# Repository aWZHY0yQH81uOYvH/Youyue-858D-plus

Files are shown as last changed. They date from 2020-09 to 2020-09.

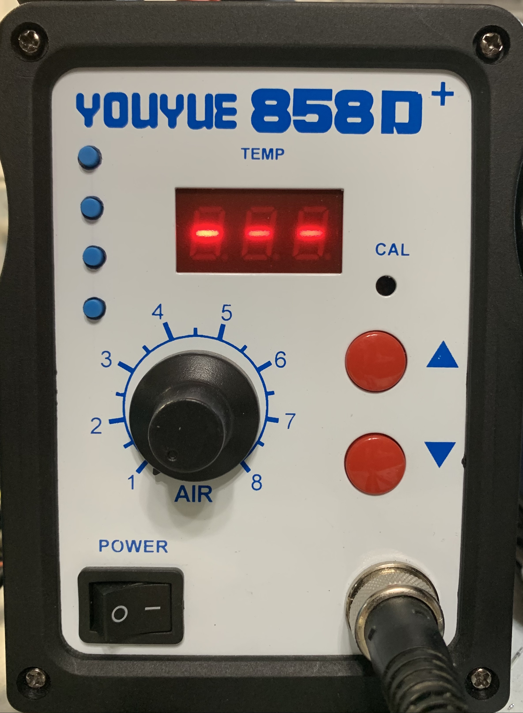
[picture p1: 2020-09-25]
Docs/mods/preset-buttons/front panel.jpg

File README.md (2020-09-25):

Youyue-858D-plus
================

Custom firmware and adapter PCB for the Youyue 858D+ with MK1841D3 stock MCU

This board and firmware is designed only for the ATmega328*PB* because it makes use of its extra port E I/O.

This repo includes a PCB that contains all the mods I could find:
* wguibas's MK1841D3 to AVR pinout adapting
* madworm's fancy fan speed commutation sensing
* RaiHei's buzzer
* Gabse's max fan speed cooldown
* 4 buttons for recalling preset temperatures
* Some extra I/O breakout for more hacking

Order the parts and PCB in the PCB folder. Then, use [this instructable](https://www.instructables.com/id/858D-SMD-Hot-Ait-Reflow-Station-Hack/) as a general guide. Add some buttons to the front panel for the presets.

There is a 'user manual' of sorts in the 'Docs' folder.

Some videos showing the progress from 'stock firmware' with massive temperature overshoot
towards almost no overshoot at all.

https://www.youtube.com/playlist?list=PLONcxJMOrdyeYuEgM6qhCllZelN6gPjrT

Please note:

Although this device looks very much like ones sold by 'Atten' and others, the innards
are not necessarily the same. The heater / wand are probably the same, but I know that
e.g. the 'Atten 858D' uses a different mainboard with a different brand microcontroller.

Naturally, this firmware will only work 'as is' for the exact mcu / mainboard combination I have.
Please see the 'Docs' folder for schematic and PCB photos.

Compiling/Development
=====================
Since this version of the firmware uses the PB variant of the chip, you need to use the makefile. You may need to adjust `ISP_PROG` and `AVRDUDE_ARD_PROGRAMMER` in the makefile depending on what programmer you have.
* Do `make` to just compile the project.
* Do `make ispload` to compile and upload the project.
* If you don't want to edit the firmware, you can just follow the instructions in the binaries folder to upload without compiling.

---

Safety information / disclaimer:
================================

Making any modifications to this device may cause you irreversible physical harm or worse.
You do this at your own risk. 

There is a significant risk of lethal electrical shock, so if you still insist of doing so, make sure to
ALWAYS UNPLUG THE MAINS CABLE before dismantling the device. Check repeatedly.

If you have an isolation transformer - do use it.

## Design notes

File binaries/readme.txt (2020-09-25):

Programming
===========

Fuses
=====

AVRDUDE command line for writing the FUSE settings to the chip (required once):

avrdude -C avrdude.conf -c <programmer> -P <port,optional> -p <target-mcu> -v -U lfuse:w:0xAA:m -U hfuse:w:0xBB:m -U efuse:w:0xCC:m -U lock:w:0xDD:m

EX: avrdude -C avrdude.conf -p m328pb -c atmelice_isp -U lfuse:w:0xE2:m -U hfuse:w:0xDF:m -U efuse:w:0xfd:m

It's okay if the extended fuses fail verification because some of them are undefined.

L-FUSE: 0xE2
H-FUSE: 0xDF
E-FUSE: 0xFD

AVR FUSE calculator:
====================

(1) http://www.engbedded.com/fusecalc
(2) http://eleccelerator.com/fusecalc/fusecalc.php

Flashing
========

AVRDUDE command line for writing code to the chip:

avrdude -C avrdude.conf -c <programmer> -P <port,optional> -p <target-mcu> -v -e -U flash:w:<hexfile>:i

EX: avrdude -C avrdude.conf -p m328pb -c atmelice_isp -U flash:w:build-uno/Youyue-858D-plus.hex

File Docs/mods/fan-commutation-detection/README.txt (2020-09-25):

Please have a look at this repository for a working prototype:

https://github.com/madworm/Youyue-858D-plus-FAN-speed-mod

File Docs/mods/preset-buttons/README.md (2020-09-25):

Preset Buttons
==============

Just drill some holes in the free space in the front panel and hot glue some small tactile buttons in.

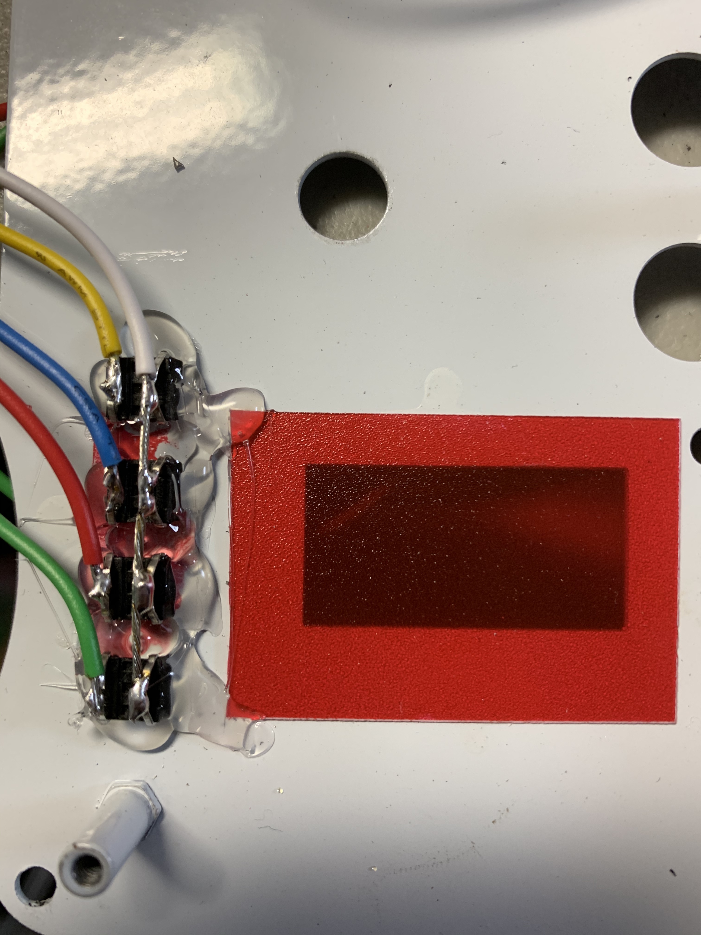
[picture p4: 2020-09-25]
Docs/mods/preset-buttons/buttons inside.jpg

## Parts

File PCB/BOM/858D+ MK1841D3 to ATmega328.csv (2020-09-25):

Id | Designator | Package | Quantity | Designation | DigiKey Part Number
1 | Q2,Q1 | SOT-23_Handsoldering | 2 | 2N7002 | 1727-8643-1-ND
2 | D1 | D_SOD-123 | 1 | D_Small | BAS16HT3GOSCT-ND
3 | R11 | R_0603_1608Metric_Pad1.05x0.95mm_HandSolder | 1 | 220 | CR0603-JW-221ELFCT-ND
4 | U2 | TQFP-32_7x7mm_P0.8mm | 1 | ATmega328PB-AU | ATMEGA328PB-AN-ND
5 | J2 | PinHeader_2x03_P2.54mm_Vertical | 1 | ICSP
6 | R10,R9,R8,R7,R4,R1 | R_0603_1608Metric_Pad1.05x0.95mm_HandSolder | 6 | 10k | CR0603-JW-103ELFCT-ND
7 | JP1 | SolderJumper-3_P2.0mm_Open_TrianglePad1.0x1.5mm | 1 | SolderJumper_3_Open
8 | J3 | DIP-20_W7.62mm_LongPads | 1 | MK1841D3
9 | U1 | SOIC-8_3.9x4.9mm_P1.27mm | 1 | LM2904 | LM2904EDR2GOSCT-ND
10 | TP3 | TestPoint_THTPad_D2.5mm_Drill1.2mm | 1 | FAN_SPEED
11 | TP2 | TestPoint_THTPad_D2.5mm_Drill1.2mm | 1 | COMP_ADJ
12 | TP1 | TestPoint_THTPad_D2.5mm_Drill1.2mm | 1 | Vref
13 | SW1 | SolderWirePad_1x05_P3.81mm_Drill1.2mm | 1 | SW_Push_4x
14 | RV2,RV1 | Potentiometer_Bourns_TC33X_Vertical | 2 | 10k | TC33X-103ECT-ND
15 | R6 | R_0603_1608Metric_Pad1.05x0.95mm_HandSolder | 1 | 100k | CR0603-JW-104ELFCT-ND
16 | R5 | R_0603_1608Metric_Pad1.05x0.95mm_HandSolder | 1 | 1M | CR0603-JW-105ELFCT-ND
17 | R3,R2 | R_0603_1608Metric_Pad1.05x0.95mm_HandSolder | 2 | 390 | RMCF0603JT390RCT-ND
18 | J5 | SolderWirePad_1x01_Drill1.2mm | 1 | FAN_MAX_SPEED
19 | J4 | SolderWirePad_1x04_P3.81mm_Drill1.2mm | 1 | Extra
20 | J1 | SolderWirePad_1x01_Drill1.2mm | 1 | ISENSE
21 | C6,C5,C3,C2,C1 | C_0603_1608Metric_Pad1.05x0.95mm_HandSolder | 5 | 100n | 1276-1935-1-ND
22 | C4 | C_0603_1608Metric_Pad1.05x0.95mm_HandSolder | 1 | 1µ | 1276-1866-1-ND
23 | BZ1 | Buzzer_12x9.5RM6.5 | 1 | Buzzer | 668-1470-ND

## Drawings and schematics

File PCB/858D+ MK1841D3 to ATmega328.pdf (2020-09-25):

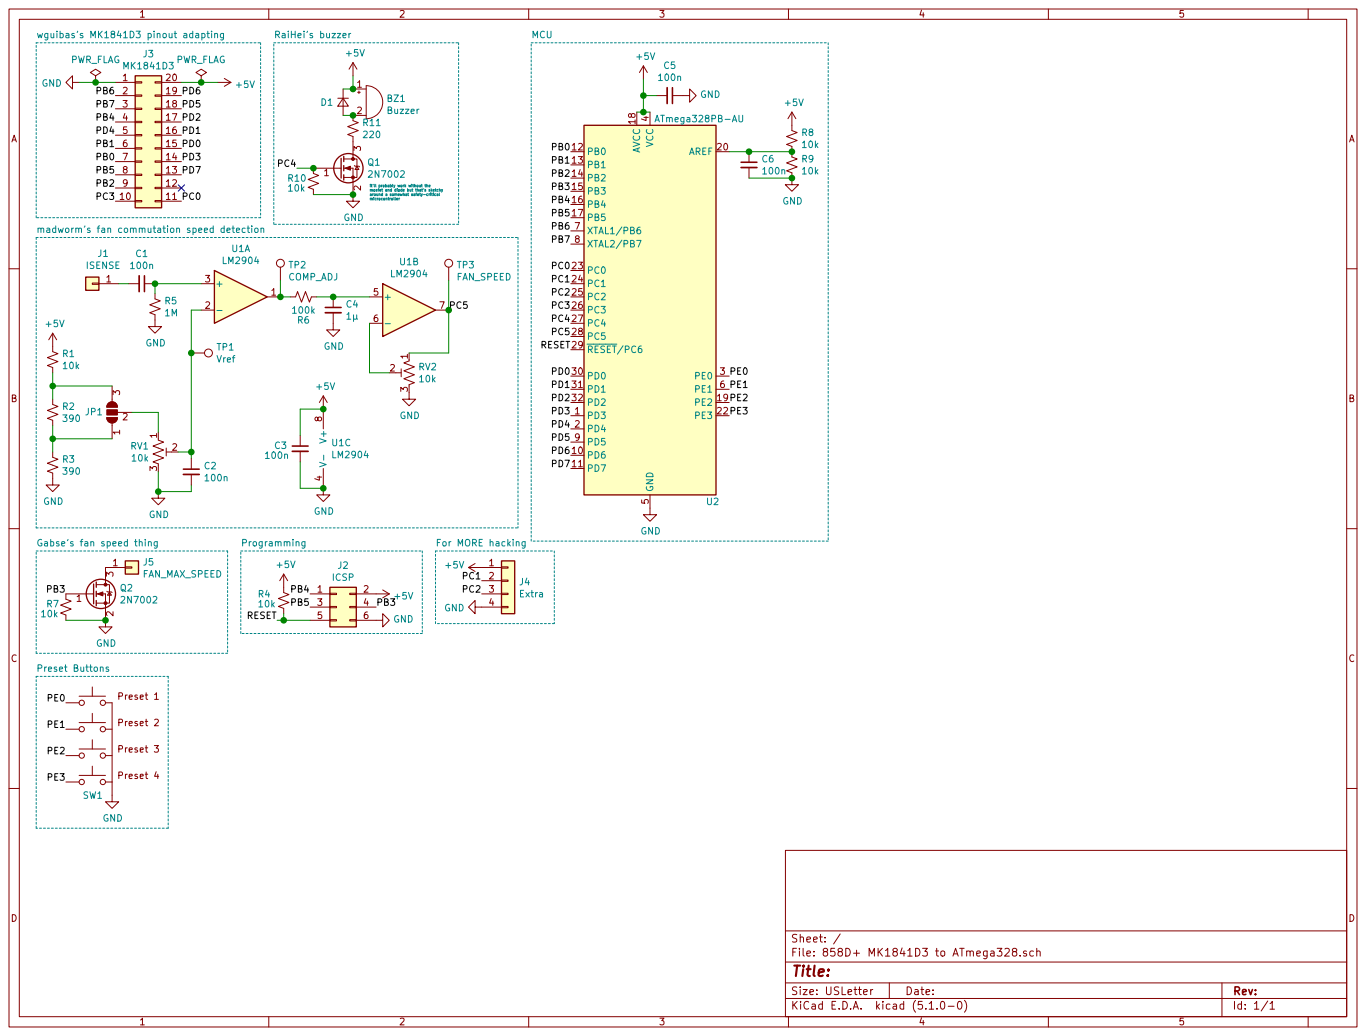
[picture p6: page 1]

itll probably work without the mosfet and diode but thats sketchy around a somewhat safety-critical microcontroller Gabses fan speed thing

100n GND madworms fan commutation speed detection

For MORE hacking Preset Buttons

File: 858D+ MK1841D3 to ATmega328.sch Sheet: /

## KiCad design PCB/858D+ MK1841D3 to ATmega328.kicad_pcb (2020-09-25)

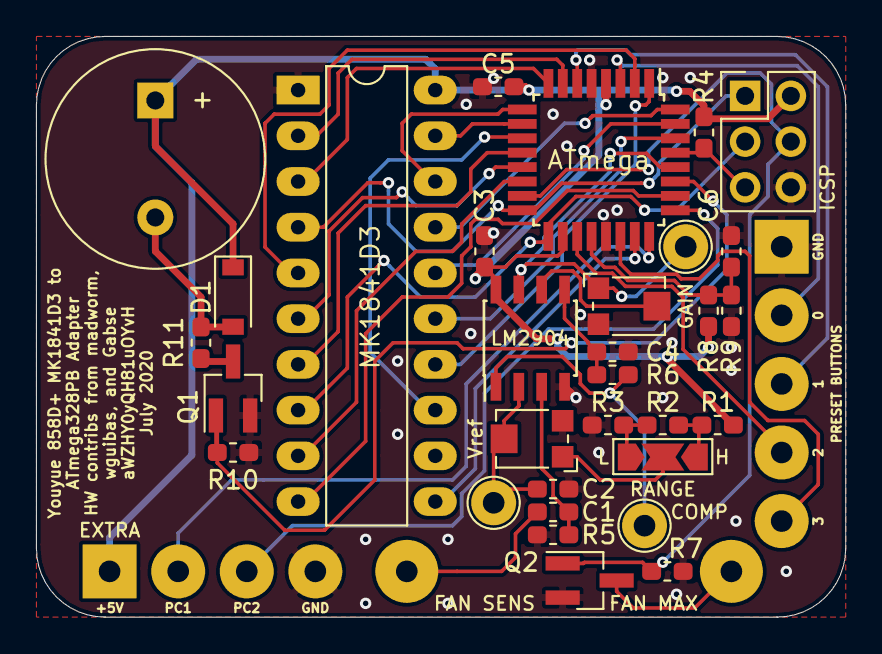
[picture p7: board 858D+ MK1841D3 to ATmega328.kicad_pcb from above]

Board: 2 copper layers, 45.0 x 32.3 mm, 35 parts (0 on the bottom side), 42 nets.

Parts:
BZ1: Buzzer; Buzzer_12x9.5RM6.5
C1, C2, C3, C5, C6: 100n; C_0603_1608Metric_Pad1.05x0.95mm_HandSolder
C4: 1µ; C_0603_1608Metric_Pad1.05x0.95mm_HandSolder
D1: D_Small; D_SOD-123
J1: ISENSE; SolderWirePad_1x01_Drill1.2mm
J2: ICSP; PinHeader_2x03_P2.54mm_Vertical
J3: MK1841D3; DIP-20_W7.62mm_LongPads
J4: Extra; SolderWirePad_1x04_P3.81mm_Drill1.2mm
J5: FAN_MAX_SPEED; SolderWirePad_1x01_Drill1.2mm
JP1: SolderJumper_3_Open; SolderJumper-3_P2.0mm_Open_TrianglePad1.0x1.5mm
Q1, Q2: 2N7002; SOT-23_Handsoldering
R1, R4, R7, R8, R9, R10: 10k; R_0603_1608Metric_Pad1.05x0.95mm_HandSolder
R2, R3: 390; R_0603_1608Metric_Pad1.05x0.95mm_HandSolder
R5: 1M; R_0603_1608Metric_Pad1.05x0.95mm_HandSolder
R6: 100k; R_0603_1608Metric_Pad1.05x0.95mm_HandSolder
R11: 220; R_0603_1608Metric_Pad1.05x0.95mm_HandSolder
RV1, RV2: 10k; Potentiometer_Bourns_TC33X_Vertical
SW1: SW_Push_4x; SolderWirePad_1x05_P3.81mm_Drill1.2mm
TP1: Vref; TestPoint_THTPad_D2.5mm_Drill1.2mm
TP2: COMP_ADJ; TestPoint_THTPad_D2.5mm_Drill1.2mm
TP3: FAN_SPEED; TestPoint_THTPad_D2.5mm_Drill1.2mm
U1: LM2904; SOIC-8_3.9x4.9mm_P1.27mm
U2: ATmega328PB-AU; TQFP-32_7x7mm_P0.8mm

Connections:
+5V: BZ1.1, C3.1, C5.2, D1.1, J2.2, J3.20, J4.1, R1.1, R4.1, R8.1, U1.8, U2.4, U2.18
/PB0: J3.7, U2.12
/PB1: J3.6, U2.13
/PB2: J3.9, U2.14
/PB3: J2.4, Q2.1, R7.1, U2.15
/PB4: J2.1, J3.4, U2.16
/PB5: J2.3, J3.8, U2.17
/PB6: J3.2, U2.7
/PB7: J3.3, U2.8
/PC0: J3.11, U2.23
/PC1: J4.2, U2.24
/PC2: J4.3, U2.25
/PC3: J3.10, U2.26
/PC4: Q1.1, R10.1, U2.27
/PC5: RV2.1, TP3.1, U1.7, U2.28
/PD0: J3.15, U2.30
/PD1: J3.16, U2.31
/PD2: J3.17, U2.32
/PD3: J3.14, U2.1
/PD4: J3.5, U2.2
/PD5: J3.18, U2.9
/PD6: J3.19, U2.10
/PD7: J3.13, U2.11
/PE0: SW1.2, U2.3
/PE1: SW1.3, U2.6
/PE2: SW1.4, U2.19
/PE3: SW1.5, U2.22
/RESET: J2.5, R4.2, U2.29
GND: C2.2, C3.2, C4.2, C5.1, C6.2, J2.6, J3.1, J4.4, Q1.2, Q2.2, R3.2, R5.2, R7.2, R9.2, R10.2, RV1.3, RV2.3, SW1.1, U1.4, U2.5, U2.21
unnamed: BZ1.2, D1.2, R11.1
unnamed: C1.1, R5.1, U1.3
unnamed: C1.2, J1.1
unnamed: C2.1, RV1.2, TP1.1, U1.2
unnamed: C4.1, R6.1, U1.5
unnamed: C6.1, R8.2, R9.1, U2.20
unnamed: J5.1, Q2.3
unnamed: JP1.1, R2.2, R3.1
unnamed: JP1.2, RV1.1
unnamed: JP1.3, R1.2, R2.1
unnamed: Q1.3, R11.2
unnamed: R6.2, TP2.1, U1.1
unnamed: RV2.2, U1.6

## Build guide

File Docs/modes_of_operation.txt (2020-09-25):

Once the device (cold, wand in cradle) is turned on, it will do the following:
==============================================================================

* Display the firmware version
* Start the fan for about 2 seconds and turn it off again
* Either display "---" if the temperature is below 40°C (safe to touch)
* Or display the current temperature if the temperature is above 40°C

Fan controls:
=============

* The fan-speed is set with the potentiometer
* If the fan-speed is erratic, you need a new potentiometer
* If the wand is in the cradle and is cold (< 45°C), then fan is off
* If the wand is in the cradle and is too hot (> 60°C), the fan is on
* If the wand is out of the cradle, the fan is always on

Temperature control:
====================

* The base unit usually shows the current temperature (averaged)
* It shows the set-point, if the temperature is within +- 3°C
* Temperature can be changed with the up/down buttons
* Short button press: +- 1°C
* Long button press:  +- 10°C
* The set-point is stored in eeprom
* Temperature range: 50...500 °C
* Fan Only mode (press both buttons together shortly)
* Hold down a preset button while changing the temperature to set the temperature. Press the button again to recall.

Settings:
=========

* Config mode is entered by pressing both buttons at the same time 
  for a longer time
* When Settings are changed, the heater is always off
* The state of the fan is not changed when entering config mode
* The display will show an abbreviated name for each parameter
* Going to the next one is done by pressing both buttons at the same time

  p)            p_gain    0...999
  i)            i_gain    0...999
  d)            d_gain    0...999
ith)       i_threshold    0...100
tof)  temp_offset_corr -100...100
tpl)temp_multiplicator   10...40
avg)     temp_averages  100...999
slp)       slp_timeout    0...30
del)     fan_off_delay    0...60
adc)   display_adc_raw	  0...1
fcl)   fan_current_min    0...999 (not used)
fch)   fan_current_max    0...999 (not used)
fsl)     fan_speed_min  120...180
fsh)     fan_speed_max  300...400

* fsl/fsh and fcl/fch are depending on CURRENT_SENSE_MOD compile time option

* All parameters stored / loaded from EEPROM are checked if within range
* Invalid parameters are reset to their default values when stored / loaded
  (see youyue858d.h)

i_threshold: temperature range (+-) that determines the switch between PD and PID
             if the temperature is far away from the set-point, PD-control is used
             if the temperature is within range, PID-control is used to stabilize

temp_offset_corr: can be used to correct a temperature difference between the display
                  and the temperature measured with an external sensor at the nozzle

                  increase, if you measure too high a temperature			
                  decrease, if measured temperature is too low

display_adc_raw:  display the raw ADC value instead of derived temperature
                  temperature regulation works as usual
                  very useful for creating calibration data (T-measured vs. ADC value)

Fan Speed/Current:
==================

* Can be tested when pressing up while powering on, current value is shown and updated.
* Hard reset to leave

Restoring default:
==================

* Turn the device off
* Press and hold both buttons at the same time
* Turn the device on and wait a couple of seconds
* The device will enter the PID settings menu with default value restored
* Either change the values again or turn the device off

Sleep timeout:
==============

SLP)     slp_timeout  0...30 (default: 5)

If the wand is not placed into the cradle for longer than slp_timeout, the heater
is switched off, but the fan keeps running indefinitely.

Error behaviour:
================

* If the wand is disconnected or the thermo-couple has failed or the temperature
  is above MAX_TEMP_ERR (550°C), the device will go into a "safe mode" and 
  display the error message "°C" + "Err".
  
  The heater will be turned off permanently, the fan will be turned on 
  to allow fast cool-down and the display will blink "*C" and "ERR" until power is cycled.

* If the device is powered up and the wand is not in the cradle, an error message
  will be displayed ("CrA" + "dlE"). Put the wand into the cradle for normal operation.

  This should avoid any issues with the device being accidentally powered on 
  with the wand on the table (e.g. after power outage).

* If the fan-speed on power-up (fan-test) is out of range (F-L, F-h config parameters),
  an error message "FAN" + "SPd" or "FAN" + "Cur" will be displayed.

  (This does not necessarily detect a stalled fan, as the feedback is just the
   drive voltage or current, not an actual tacho signal!)

  If you get this error on every startup with a low or high fan speed, adjust the config
  parameters for fsl/fsh (speed) or fcl/fch (current)

* If the WATCHDOG is used (by default) and the device becomes unresponsive for more
  than about 120ms AND the heater is ON, a watchdog-reset is triggered.

  THIS SHOULD NEVER HAPPEN.

  The device will turn off the heater and turn on the fan. The display will blink
  the error code "rSt" until power is cycled.

* If the "CKDIV8" FUSE bit is erroneously set when programming the firmware
  (F_CPU is divided by 8), cause a watchdog reset. See previous entry for more info.

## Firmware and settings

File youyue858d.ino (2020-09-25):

/*
 * This is a custom firmware for my 'Youyue 858D+' hot-air soldering station.
 * It may or may not be useful to you, always double check if you use it.
 *
 * V1.49
 * 2020    - aWZHY0yQH81uOYvH
 * 2018    - Gabs'e
 * 2016    - RaiHei
 * 2015/16 - Robert Spitzenpfeil
 * 2015    - Moritz Augsburger
 *
 * License: GNU GPL v2
 *
 *
 * Changes by aWZHY0yQH81uOYvH:
 * - Added four preset buttons to quickly recall temperatures
 * - Changed standby display back to "---" from "STB" because in my opinion it looks nicer :-)
 * - Added the bottom segment to the 9
 * - Removed flashing display while changing the temperature
 * - Made the first temp change button press not change the set temp (for checking what it's set to)
 *
 * Changes by Gabs'e: (Tested on a Uvistar 858D with MK1841D3 modded to ATMEGA 328P, Fan current sensing , and Maximum FAN speed. Board 2016.06.09)
 * - Added an output (arduino pin 11) for a transistor switching FAN to maximum speed to cool down faster
 * - Moved the Cradle check behind the FAN Test to save some time at startup
 *
 * Changes by RaiHei: (Tested on a Kaleep branded 858D+ delivered with MK1841D3 chip and modded to ATMEGA 328P. Board version 2015.08.21)
 * - Added an output (arduino pin 18) for a buzzer which will beep on the following events:
 *   Power on (high beep)
 *   Set temperature reached (only one time after removing gun from cradle and after changing temperature with the key buttons) (high beep)
 *   Put gun correctly back in cradle (low beep)
 *   Setted timeout reached (low beep)
 *   Keypress (comment out "#define KEYBEEP" in youyue858d.h to disable) (very high beep)
 * - Added a multiplicator entry (TPL) to setup menu for stations with samsung or MK1841D3 chip
 *   For stations delivered with atmel chip set multiplicator to 10 (=1, default), for stations with MK1841D3 set to 21-24 (=2.1-2.4)
 *   (According to the forum on some stations a value between 2.3-2.4 is correct, on my station with MK1841D3 2.1 was correct)
 *   Possible values 10 to 40 (= multiplicator 1.0-4.0)
 *   This change avoids a seperate firmware version (thanks wguibas!) for machines delivered with non atmel chips
 * - Added raw ADC value monitoring to the overtemperature shutdown process, because when you fiddle around with the multiplicator 
 *   and set it wrong, temperature input may overflow which results in no shutdown on too high temperatures.
 *   Station will shut down and show "°C ERR" when analog input for temperature reaches 1000 (analog input is 10bit so max value is 1023)
 * - Changed standby display from "---" to "STB" because in my opinion it looks nicer :-)
 * - Added a delay time entry (DEL) to the setup menu which kicks in when the fan_off temperature is reached (default 45°C) 
 *   to avoid fan off-on-off-on-off bevaviour because temperature rises to fan_on temperature again after fan was switched off.
 *   Delay will only be active if a temperature of 100°C was reached.
 *   Possible values 0 to 60 seconds 
 * - Changed back max temperature to 450°C and shutdown temperature to 500°C because (depending on cal pot setting) 500° can lead to overflow of temp analog input.
 *
 */

/*
 *  Make sure to read and understand '/Docs/modes_of_operation.txt'
 *
 * DO NOT USE A BOOTLOADER WITH THE WATCHDOG TIMER
 * 
 * ISP CODE UPLOAD ONLY
 * 
 * Change options in the .h file
 *
 */
#define buzzer 18
#define FW_MAJOR_V 1
#define FW_MINOR_V_A 4
#define FW_MINOR_V_B 9
/*
 * PC5: FAN-speed (A5 in Arduino lingo) (OK)
 * PC3: TIP122.base --> FAN (OK)
 * PC2: fan-current-sense mod (OPTIONAL) - see Docs folder
 * PC0: ADC <-- amplif. thermo couple voltage (A0 in Arduino lingo) (OK)
 * #21: AREF <--- about 2.5V as analog reference for ADC
 * PB1: opto-triac driver !! THIS IS DANGEROUS TO USE !! (OK)
 * PB3: FAN to maximum output (OPTIONAL)
 *
 * PB0: 7-seg digit 0 [common Anode] (OK) 
 * PB7: 7-seg digit 1 [common Anode] (OK)
 * PB6: 7-seg digit 2 [common Anode] (OK)
 *
 * PD0: 7-seg top (OK)
 * PD1: 7-seg bottom left (OK)
 * PD2: 7-seg bottom (OK)
 * PD3: 7-seg top left (OK)
 * PD4: 7-seg dot (OK)
 * PD5: 7-seg bottom right (OK)
 * PD6: 7-seg middle (OK)
 * PD7: 7-seg top right (OK)
 *
 * PB5: SW1 (button1) (OK)
 * PB2: SW2 (button2) (OK)
 * PB4: reed switch (wand cradle sensor) (OK)
 *
 * PE0: Preset 1
 * PE1: Preset 2
 * PE2: Preset 3
 * PE3: Preset 4
 *
 */

#include <avr/io.h>
#include <avr/wdt.h>
#include <avr/interrupt.h>
#include <stdint.h>
#include <EEPROM.h>
#include "youyue858d.h"

uint8_t fb[3] = { 0xFF, 0xFF, 0xFF };	// dig0, dig1, dig2
framebuffer_t framebuffer = { 0x00, 0x00, 0x00, 0, 0, 0, 0 };

CPARAM p_gain = { 0, 999, P_GAIN_DEFAULT, P_GAIN_DEFAULT, 2, 3 };	// min, max, default, value, eep_addr_high, eep_addr_low
CPARAM i_gain = { 0, 999, I_GAIN_DEFAULT, I_GAIN_DEFAULT, 4, 5 };
CPARAM d_gain = { 0, 999, D_GAIN_DEFAULT, D_GAIN_DEFAULT, 6, 7 };
CPARAM i_thresh = { 0, 100, I_THRESH_DEFAULT, I_THRESH_DEFAULT, 8, 9 };
CPARAM temp_offset_corr = { -100, 100, TEMP_OFFSET_CORR_DEFAULT, TEMP_OFFSET_CORR_DEFAULT, 10, 11 };
CPARAM temp_setpoint = { 50, 450, TEMP_SETPOINT_DEFAULT, TEMP_SETPOINT_DEFAULT, 12, 13 }; //rh450
CPARAM temp_averages = { 100, 999, TEMP_AVERAGES_DEFAULT, TEMP_AVERAGES_DEFAULT, 14, 15 };
CPARAM slp_timeout = { 0, 30, SLP_TIMEOUT_DEFAULT, SLP_TIMEOUT_DEFAULT, 16, 17 };
CPARAM fan_only = { 0, 1, 0, 0, 26, 27 };
CPARAM display_adc_raw = { 0, 1, 0, 0, 28, 29 };
CPARAM temp_multiplicator = { 10, 40, TEMP_MULTIPLICATOR_DEFAULT, TEMP_MULTIPLICATOR_DEFAULT, 30, 31 }; 
CPARAM fan_off_delay = { 0, 60, FAN_OFF_DELAY_DEFAULT, FAN_OFF_DELAY_DEFAULT, 32, 33 }; 
CPARAM preset_0 = {50, 450, TEMP_SETPOINT_DEFAULT, TEMP_SETPOINT_DEFAULT, 34, 35};
CPARAM preset_1 = {50, 450, TEMP_SETPOINT_DEFAULT, TEMP_SETPOINT_DEFAULT, 36, 37};
CPARAM preset_2 = {50, 450, TEMP_SETPOINT_DEFAULT, TEMP_SETPOINT_DEFAULT, 38, 39};
CPARAM preset_3 = {50, 450, TEMP_SETPOINT_DEFAULT, TEMP_SETPOINT_DEFAULT, 40, 41};

#ifdef CURRENT_SENSE_MOD
CPARAM fan_current_min = { 0, 999, FAN_CURRENT_MIN_DEFAULT, FAN_CURRENT_MIN_DEFAULT, 22, 23 };
CPARAM fan_current_max = { 0, 999, FAN_CURRENT_MAX_DEFAULT, FAN_CURRENT_MAX_DEFAULT, 24, 25 };
#else
//
// See youyue858d.h if you want to use the 'FAN-speed mod' (HW changes required)
// The following 2 CPARAM lines need changes in that case
//
CPARAM fan_speed_min = { 0, 999, FAN_SPEED_MIN_DEFAULT, FAN_SPEED_MIN_DEFAULT, 18, 19 };
CPARAM fan_speed_max = { 0, 999, FAN_SPEED_MAX_DEFAULT, FAN_SPEED_MAX_DEFAULT, 20, 21 };
#endif

volatile uint8_t key_state;	// debounced and inverted key state: bit = 1: key pressed
volatile uint8_t key_press;	// key press detect
volatile uint8_t key_rpt;	// key long press and repeat
volatile uint8_t display_blink;

bool cradlebeep = true;
bool timeoutbeep = true;
bool hasheated = false;
bool firstbeep = true;
int tcounter = 0; // timer for fan off delay
int scounter = 0; // timer to debounce beep when putting gun in cradle

uint8_t temp_setpoint_save = 0;
int32_t button_input_time = 0;
uint32_t preset_debounce = 0;
uint8_t preset_execute = 0;

int main(void)
{
	init();			// make sure the Arduino-specific stuff is up and running (timers... see 'wiring.c')

	setup_858D();

#ifdef DISPLAY_MCUSR
	HEATER_OFF;
	FAN_ON;
	display_number(_mcusr);
	MCUSR = 0;
	//
	// ATmega168 MCUSR (MSB to LSB): x-x-x-x-WDRF-BORF-EXTRF-PORF
	//
	delay(1000);
#endif

#ifdef USE_WATCHDOG
	if (_mcusr & _BV(WDRF)) {
		// there was a watchdog reset - should never ever happen
		HEATER_OFF;
		FAN_ON;
    FAN_MAX_ON;
		while (1) {
			display_string("RST");
			delay(1000);
			clear_display();
			delay(1000);
		}
	}
#endif

	show_firmware_version();
	test_F_CPU_with_watchdog();
	fan_test();

#ifdef USE_WATCHDOG
	watchdog_on();
#endif

#ifdef DEBUG
	Serial.begin(2400);
	Serial.println("\nRESET");
#endif

	while (1) {
#ifdef DEBUG
		int32_t start_time = micros();
#endif
		static int16_t temp_inst = 0;
		static int32_t temp_accu = 0;
		static int16_t temp_average = 0;
		static int16_t temp_average_previous = 0;

		static int16_t heater_ctr = 0;
		static int16_t heater_duty_cycle = 0;
		static int16_t error = 0;
		static int32_t error_accu = 0;
		static int16_t velocity = 0;
		static float PID_drive = 0;

		static int32_t temp_setpoint_saved_time = 0;

		static uint32_t heater_start_time = 0;

		uint16_t adc_raw = analogRead(A0);	// need raw value later, store it here and avoid 2nd ADC read

		temp_inst = ((adc_raw*10)/temp_multiplicator.value) + temp_offset_corr.value; 
    
		if (temp_inst < 0) {
			temp_inst = 0;
		}
		// pid loop / heater handling
		if (fan_only.value == 1 || REEDSW_CLOSED) {
			HEATER_OFF;
			heater_start_time = millis();
			clear_dot();
		} else if (REEDSW_OPEN && (temp_setpoint.value >= temp_setpoint.value_min) && (temp_average < MAX_TEMP_ERR) && ((millis() - heater_start_time) < ((uint32_t) (slp_timeout.value) * 60 * 1000))) {

			FAN_ON;

			error = temp_setpoint.value - temp_average;
			velocity = temp_average_previous - temp_average;

			if (abs(error) < i_thresh.value) {
				// if close enough to target temperature use PID control
				error_accu += error;
			} else {
				// otherwise only use PD control (avoids issues with error_accu growing too large
				error_accu = 0;
			}

			PID_drive =
			    error * (p_gain.value / P_GAIN_SCALING) + error_accu * (i_gain.value / I_GAIN_SCALING) +
			    velocity * (d_gain.value / D_GAIN_SCALING);

			heater_duty_cycle = (int16_t) (PID_drive);

			if (heater_duty_cycle > HEATER_DUTY_CYCLE_MAX) {
				heater_duty_cycle = HEATER_DUTY_CYCLE_MAX;
			}

			if (heater_duty_cycle < 0) {
				heater_duty_cycle = 0;
			}

			if (heater_ctr < heater_duty_cycle) {
				set_dot();
				HEATER_ON;
			} else {
				HEATER_OFF;
				clear_dot();
			}

			heater_ctr++;
			if (heater_ctr == PWM_CYCLES) {
				heater_ctr = 0;
			}
		} else {
			HEATER_OFF;
			clear_dot();
		}

		static uint16_t temp_avg_ctr = 0;

		temp_accu += temp_inst;
		temp_avg_ctr++;

		if (temp_avg_ctr == (uint16_t) (temp_averages.value)) {
			temp_average_previous = temp_average;
			temp_average = temp_accu / temp_averages.value;
			temp_accu = 0;
			temp_avg_ctr = 0;
		}
		// fan/cradle handling
		if (cradlebeep == false && REEDSW_CLOSED)
		{
		 if (scounter < 300)
		 {
		  scounter++;
		  delay(1);
		 }
		 else
		 {
		  scounter = 0;
		  tone(buzzer, 1000, 100);
		  cradlebeep = true;
		 }
		}
		if (cradlebeep == true && REEDSW_OPEN)
		{
		  cradlebeep = false;
		  firstbeep = true;
		  timeoutbeep = false;
		}
		if ((millis() - heater_start_time) > ((uint32_t) (slp_timeout.value) * 60 * 1000) && timeoutbeep == false)
		{
		  tone(buzzer, 1000, 100);
		  timeoutbeep = true;
		}

		if (REEDSW_OPEN && temp_average > 100)
		{
		  hasheated = true;
		}
	
		if (REEDSW_CLOSED && fan_only.value == 0 && (temp_average > FAN_OFF_TEMP)) {                // In cradle cool down heating mode cooling
		  FAN_ON;
		  FAN_MAX_ON;
		} else if (REEDSW_CLOSED && fan_only.value == 1 && (temp_average > FAN_OFF_TEMP_FANONLY)) { // In cradle cool down FAN mode cooling
		  FAN_ON;
		  FAN_MAX_ON;
		}else if (REEDSW_CLOSED && fan_only.value == 1 && (temp_average <= FAN_OFF_TEMP_FANONLY)) { // In cradle cool down FAN mode cold
		  FAN_OFF;
		  FAN_MAX_OFF;
		} else if (REEDSW_CLOSED && fan_only.value == 0 && (temp_average <= FAN_OFF_TEMP)) {        // In cradle cool down heating mode cold
		   if (tcounter < (fan_off_delay.value*1000) && hasheated == true)
		   {
			tcounter++;
			delay(1);
		   }
		   else
		   {
			tcounter = 0;
			hasheated = false;
			FAN_OFF;
			FAN_MAX_OFF;
		   }
	
		} else { //  Outside cradle
		  FAN_ON;
		  FAN_MAX_OFF;
		}
		
		// preset key handling
		uint8_t preset_keys=get_preset_keys();
		if(preset_keys) {
			preset_execute=preset_keys;
			preset_debounce=millis();
		} else if(preset_execute && preset_debounce+25 < millis()) { // update on release
			switch(preset_execute) {
				case 0b00000001:
					temp_setpoint.value=preset_0.value;
					temp_setpoint_save=1;
					break;
				case 0b00000010:
					temp_setpoint.value=preset_1.value;
					temp_setpoint_save=1;
					break;
				case 0b00000100:
					temp_setpoint.value=preset_2.value;
					temp_setpoint_save=1;
					break;
				case 0b00001000:
					temp_setpoint.value=preset_3.value;
					temp_setpoint_save=1;
					break;
			}
			button_input_time = millis();
			preset_execute=0;
		}
		
		// menu key handling
		if (get_key_short(1 << KEY_UP)) {
			if (temp_setpoint.value < temp_setpoint.value_max) {
				update_temp_setpoint(temp_setpoint.value+1);
			firstbeep = true;
			#ifdef KEYBEEP
			  tone(buzzer, 2000, 20);
			#endif
			}
			button_input_time = millis();
		} else if (get_key_short(1 << KEY_DOWN)) {
			if (temp_setpoint.value > temp_setpoint.value_min) {
				update_temp_setpoint(temp_setpoint.value-1);
			firstbeep = true;
			#ifdef KEYBEEP
			  tone(buzzer, 2000, 20);
			#endif
			}
			button_input_time = millis();
		} else if (get_key_long_r(1 << KEY_UP) || get_key_rpt_l(1 << KEY_UP)) {
			if (temp_setpoint.value < (temp_setpoint.value_max - 10)) {
				update_temp_setpoint(temp_setpoint.value+10);
			firstbeep = true;
			#ifdef KEYBEEP
			  tone(buzzer, 2000, 20);
			#endif
			} else {
				update_temp_setpoint(temp_setpoint.value_max);
			}
			button_input_time = millis();
		} else if (get_key_long_r(1 << KEY_DOWN) || get_key_rpt_l(1 << KEY_DOWN)) {
			if (temp_setpoint.value > (temp_setpoint.value_min + 10)) {
				update_temp_setpoint(temp_setpoint.value-10);
			firstbeep = true;
			#ifdef KEYBEEP
			  tone(buzzer, 2000, 20);
			#endif
			} else {
				update_temp_setpoint(temp_setpoint.value_min);
			}
			button_input_time = millis();
		} else if (get_key_common_l(1 << KEY_UP | 1 << KEY_DOWN)) {
			HEATER_OFF;	// security reasons, delay below!
#ifdef USE_WATCHDOG
			watchdog_off();
#endif
			delay(uint16_t(20.48 * (REPEAT_START - 3) + 1));
			if (get_key_long_r(1 << KEY_UP | 1 << KEY_DOWN)) {
				change_config_parameter(&p_gain, "P");
				change_config_parameter(&i_gain, "I");
				change_config_parameter(&d_gain, "D");
				change_config_parameter(&i_thresh, "ITH");
				change_config_parameter(&temp_offset_corr, "TOF");
        		change_config_parameter(&temp_multiplicator, "TPL");
				change_config_parameter(&temp_averages, "AVG");
				change_config_parameter(&slp_timeout, "SLP");
        		change_config_parameter(&fan_off_delay, "DEL");       
				change_config_parameter(&display_adc_raw, "ADC");
#ifdef CURRENT_SENSE_MOD
				change_config_parameter(&fan_current_min, "FCL");
				change_config_parameter(&fan_current_max, "FCH");
#else
				change_config_parameter(&fan_speed_min, "FSL");
				change_config_parameter(&fan_speed_max, "FSH");
#endif
			} else {
				get_key_press(1 << KEY_UP | 1 << KEY_DOWN);	// clear inp state
				fan_only.value ^= 0x01;
				temp_setpoint_save = 1;
				if (fan_only.value == 0) {
					button_input_time = millis();	// show set temp after disabling fan only mode
				}
				display_blink = 0;	// make sure we start displaying "FAN" or set temp
			}
#ifdef USE_WATCHDOG
			watchdog_on();
#endif
		}
		// security first!
		if (temp_average >= MAX_TEMP_ERR || adc_raw > 1000 ) { //check adc value also to avoid endless heating
			// something might have gone terribly wrong
			HEATER_OFF;
			FAN_ON;
      FAN_MAX_ON;
#ifdef USE_WATCHDOG
			watchdog_off();
#endif
			while (1) {
				// stay here until the power is cycled
				// make sure the user notices the error by blinking "FAN"
				// and don't resume operation if the error goes away on its own
				//
				// possible reasons to be here:
				//
				// * wand is not connected (false temperature reading)
				// * thermo couple has failed
				// * true over-temperature condition
				//
				display_string("*C");
				delay(1000);
				display_string("ERR");
				delay(2000);
				clear_display();
				delay(1000);
			}
		}
		// display output
		if ((millis() - button_input_time) < SHOW_SETPOINT_TIMEOUT) {
			if (display_blink < 5 && millis() - button_input_time > 500) {
				clear_display();
			} else {
				display_number(temp_setpoint.value);	// show temperature setpoint
			}
		} else {
			if (temp_setpoint_save) {
				set_eeprom_saved_dot();
				eep_save(&temp_setpoint);
				eep_save(&preset_0);
				eep_save(&preset_1);
				eep_save(&preset_2);
				eep_save(&preset_3);
				eep_save(&fan_only);
				temp_setpoint_saved_time = millis();
				temp_setpoint_save = 0;
			} else if (temp_average <= SAFE_TO_TOUCH_TEMP) {
				if (fan_only.value == 1) {
					display_string("FAN");
				} else {
					display_string("---");
				}
			} else if (fan_only.value == 1) {
				if (display_blink < 20) {
					display_string("FAN");
				} else {
					display_number(temp_average);
				}
			} else if (display_adc_raw.value == 1) {
				display_number(adc_raw);
			} else if (abs((int16_t) (temp_average) - (int16_t) (temp_setpoint.value)) < TEMP_REACHED_MARGIN) {
				if (firstbeep == true) // beep one time when set temperature is reached
				{
					tone(buzzer, 1500, 100);
					firstbeep = false;
				}
				display_number(temp_setpoint.value);	// avoid showing insignificant fluctuations on the display (annoying)
			} else {
				display_number(temp_average);
			}
		}

		if ((millis() - temp_setpoint_saved_time) > 500) {
			clear_eeprom_saved_dot();
		}

		fb_update();

#if defined(WATCHDOG_TEST) && defined(USE_WATCHDOG)
		// watchdog test
		if (temp_average > 100) {
			delay(150);
		}
#endif

#ifdef USE_WATCHDOG
		wdt_reset();
#endif

#ifdef DEBUG
		int32_t stop_time = micros();
		Serial.println(stop_time - start_time);
#endif
	}

}

void setup_858D(void)
{
	HEATER_OFF;
	DDRB |= _BV(PB1);	// set as output for TRIAC control

	DDRB &= ~(_BV(PB5) | _BV(PB2));	// set as inputs (switches)
	PORTB |= (_BV(PB5) | _BV(PB2));	// pull-up on

	DDRB &= ~_BV(PB4);	// set as input (reed sensor)
	PORTB |= _BV(PB4);	// pull-up on

	FAN_OFF;
	DDRC |= _BV(PC3);	// set as output (FAN control)

	DDRD |= 0xFF;		// all as outputs (7-seg segments)
	DDRB |= (_BV(PB0) | _BV(PB6) | _BV(PB7));	// 7-seg digits 1,2,3

	DDRB |= _BV(PB3); // set FAN_MAX as output
	
	DDRE = 0; // Buttons
	PORTE = 0b00001111; // Pullups


#ifdef CURRENT_SENSE_MOD
	DDRC &= ~_BV(PC2);	// set as input
#endif

	setup_timer1_ctc();	// needed for background display refresh

	analogReference(EXTERNAL);	// use external 2.5V as ADC reference voltage (VCC / 2)

	if (EEPROM.read(0) != 0x22) {
		// check if the firmware was just flashed and the EEPROM is therefore empty
		// assumption: full chip erase with ISP programmer (preserve eeprom fuse NOT set!)
		// if so, restore default parameter values & write a 'hint' to address 0
		restore_default_conf();
		EEPROM.write(0, 0x22);
	}

	if (SW0_PRESSED && SW1_PRESSED) {
		restore_default_conf();
	} else if (SW0_PRESSED) {
		display_string("FAN");
		delay(1000);
		display_string("TST");
		delay(1000);
		FAN_ON;
		while (1) {
			uint16_t fan;
			delay(500);
#ifdef CURRENT_SENSE_MOD
			fan = analogRead(A2);
#else				//CURRENT_SENSE_MOD
			fan = analogRead(A5);
#endif				//CURRENT_SENSE_MOD
			display_number(fan);
		}
	}

	eep_load(&p_gain);
	eep_load(&i_gain);
	eep_load(&d_gain);
	eep_load(&i_thresh);
	eep_load(&temp_offset_corr);
	eep_load(&temp_multiplicator);
	eep_load(&temp_setpoint);
	eep_load(&temp_averages);
	eep_load(&slp_timeout);
	eep_load(&fan_off_delay);
	eep_load(&fan_only);
	eep_load(&display_adc_raw);
	eep_load(&preset_0);
	eep_load(&preset_1);
	eep_load(&preset_2);
	eep_load(&preset_3);
#ifdef CURRENT_SENSE_MOD
	eep_load(&fan_current_min);
	eep_load(&fan_current_max);
#else
	eep_load(&fan_speed_min);
	eep_load(&fan_speed_max);
#endif
}

void clear_display(void)
{
	framebuffer.digit[0] = 255;
	framebuffer.digit[1] = 255;
	framebuffer.digit[2] = 255;
	framebuffer.dot[0] = 0;
	framebuffer.dot[1] = 0;
	framebuffer.dot[2] = 0;
	framebuffer.changed = 1;
	fb_update();
}

void display_string(const char *string)
{
	framebuffer.digit[0] = 255;
	framebuffer.digit[1] = 255;
	framebuffer.digit[2] = 255;
	framebuffer.dot[0] = 0;
	framebuffer.dot[1] = 0;
	framebuffer.dot[2] = 0;

	uint8_t ctr;

	for (ctr = 0; ctr <= 2; ctr++) {
		// read the first 3 characters of the string
		if (string[ctr] == '\0') {
			break;
		} else {
			framebuffer.digit[2 - ctr] = string[ctr];
		}
	}
	framebuffer.changed = 1;
	fb_update();
}

void change_config_parameter(CPARAM * param, const char *string)
{
	display_string(string);
	delay(750);		// let the user read what is shown

	uint8_t loop = 1;

	while (loop == 1) {
		if (get_key_short(1 << KEY_UP)) {
			if (param->value < param->value_max) {
				param->value++;
			}
		} else if (get_key_short(1 << KEY_DOWN)) {
			if (param->value > param->value_min) {
				param->value--;
			}
		} else if (get_key_long_r(1 << KEY_UP) || get_key_rpt_l(1 << KEY_UP)) {
			if (param->value < param->value_max - 10) {
				param->value += 10;
			}
		} else if (get_key_long_r(1 << KEY_DOWN) || get_key_rpt_l(1 << KEY_DOWN)) {
			if (param->value > param->value_min + 10) {
				param->value -= 10;
			}
		} else if (get_key_common(1 << KEY_UP | 1 << KEY_DOWN)) {
			loop = 0;
		}

		display_number(param->value);
	}
	set_eeprom_saved_dot();
	eep_save(param);
	delay(1000);
	clear_eeprom_saved_dot();
}

void eep_save(CPARAM * param)
{
	// make sure NOT to save invalid parameter values
	if ((param->value >= param->value_min) && (param->value <= param->value_max)) {
		// nothing to do
	} else {
		// reset to sensible minimum
		param->value = param->value_default;
	}
	EEPROM.update(param->eep_addr_high, highByte(param->value));
	EEPROM.update(param->eep_addr_low, lowByte(param->value));
}

void eep_load(CPARAM * param)
{
	int16_t tmp = (EEPROM.read(param->eep_addr_high) << 8) | EEPROM.read(param->eep_addr_low);

	// make sure NOT to restore invalid parameter values
	if ((tmp >= param->value_min) && (tmp <= param->value_max)) {
		// the value was good, so we use it
		param->value = tmp;
	} else {
		// reset to sensible value
		param->value = param->value_default;
	}
}
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

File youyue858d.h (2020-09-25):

#ifndef youyoue858d_h
#define youyoue858d_h

//#define DEBUG
#define KEYBEEP
// #define CURRENT_SENSE_MOD

#define USE_WATCHDOG
//#define DISPLAY_MCUSR
//#define WATCHDOG_TEST

typedef struct CPARAM {
	int16_t value_min;
	int16_t value_max;
	int16_t value_default;
	int16_t value;
	uint8_t eep_addr_high;
	uint8_t eep_addr_low;
} CPARAM;

typedef struct {
	char digit[3];
	bool dot[3];
	bool changed:1;
} framebuffer_t;

void change_config_parameter(CPARAM * param, const char *string);
void char_test(void);
void clear_display(void);
void clear_dot(void);
void clear_eeprom_saved_dot(void);
void display_char(uint8_t digit, uint8_t character);
void display_number(int16_t number);
void display_set_temp(int16_t number);
void display_string(const char *string);
void eep_load(CPARAM * param);
void eep_save(CPARAM * param);
void fan_test(void);
int main(void);
void restore_default_conf(void);
void segm_test(void);
void set_dot(void);
void set_eeprom_saved_dot(void);
void setup_858D(void);
void setup_timer1_ctc(void);
void show_firmware_version(void);
void fb_update(void);
void update_temp_setpoint(int);
uint8_t get_preset_keys(void);
#ifdef USE_WATCHDOG
uint8_t _mcusr __attribute__ ((section(".noinit")));
void watchdog_off_early(void) __attribute__ ((naked)) __attribute__ ((section(".init3")));	// requires R1 to be zero! (do NOT use .init1)
void watchdog_off(void);
void watchdog_on(void);
void test_F_CPU_with_watchdog(void);
#endif
uint8_t get_key_press(uint8_t key_mask);
uint8_t get_key_rpt(uint8_t key_mask);
uint8_t get_key_state(uint8_t key_mask);
uint8_t get_key_short(uint8_t key_mask);
uint8_t get_key_long(uint8_t key_mask);
uint8_t get_key_long_r(uint8_t key_mask);
uint8_t get_key_rpt_l(uint8_t key_mask);
uint8_t get_key_common(uint8_t key_mask);
uint8_t get_key_common_l(uint8_t key_mask);

#define FAN_OFF ( PORTC |= _BV(PC3) )
#define FAN_ON  ( PORTC &= ~_BV(PC3) )
#define FAN_IS_ON ( !(PINC & _BV(PC3)) )
#define FAN_IS_OFF ( PINC & _BV(PC3) )
#define FAN_MAX_ON  ( PORTB |= _BV(PB3) )
#define FAN_MAX_OFF ( PORTB &= ~_BV(PB3) )

#define DIG0_OFF ( PORTB &= ~_BV(PB0) )
#define DIG1_OFF ( PORTB &= ~_BV(PB7) )
#define DIG2_OFF ( PORTB &= ~_BV(PB6) )

#define DIG0_ON ( PORTB |= _BV(PB0) )
#define DIG1_ON ( PORTB |= _BV(PB7) )
#define DIG2_ON ( PORTB |= _BV(PB6) )

#define SEGS_OFF ( PORTD = 0xFF )

// THIS IS WHERE IT GETS DANGEROUS
// YOU CAN START A FIRE AND DO A LOT OF HARM WITH
// THE HEATER / TRIAC COMMANDS
#define TRIAC_ON ( PORTB &= ~_BV(PB1) )
#define HEATER_ON TRIAC_ON
#define TRIAC_OFF ( PORTB |= _BV(PB1) )
#define HEATER_OFF TRIAC_OFF

#define SW0_PRESSED ( !(PINB & _BV(PB5)) )
#define SW1_PRESSED ( !(PINB & _BV(PB2)) )

#define REEDSW_CLOSED ( !(PINB & _BV(PB4)) )
#define REEDSW_OPEN ( PINB & _BV(PB4) )

#define SHOW_SETPOINT_TIMEOUT 2000L

#define HEATER_DUTY_CYCLE_MAX 512L
#define PWM_CYCLES 512L

#define P_GAIN_DEFAULT 650
#define I_GAIN_DEFAULT 15
#define D_GAIN_DEFAULT 500
#define I_THRESH_DEFAULT 45
#define P_GAIN_SCALING 100.0
#define I_GAIN_SCALING 10000.0
#define D_GAIN_SCALING 25.0

#define TEMP_OFFSET_CORR_DEFAULT 0
#define TEMP_MULTIPLICATOR_DEFAULT 23
#define TEMP_SETPOINT_DEFAULT 100

#define TEMP_AVERAGES_DEFAULT 250L
#define TEMP_REACHED_MARGIN 3

#define MAX_TEMP_ERR 500L //550
#define SAFE_TO_TOUCH_TEMP 40

#define FAN_OFF_DELAY_DEFAULT 15
#define FAN_OFF_TEMP 45
#define FAN_ON_TEMP 60
#define FAN_OFF_TEMP_FANONLY (SAFE_TO_TOUCH_TEMP - 2)

//
// Comment out the following 2 #defines, if you want to use the FAN-speed mod (HW changes required)
// Continue reading below...
//
// NOT CONNECTED ON THIS PCB
// 
// #define FAN_SPEED_MIN_DEFAULT 120UL
// #define FAN_SPEED_MAX_DEFAULT 320UL

// 
// Good starting values with BLDC FAN-speed mod
//
#define FAN_SPEED_MIN_DEFAULT 450UL
#define FAN_SPEED_MAX_DEFAULT 800UL
//
// --> Don't forget to extend the ranges in the .ino <--
//
// CPARAM fan_speed_min = { 0, 999, FAN_SPEED_MIN_DEFAULT, FAN_SPEED_MIN_DEFAULT, 18, 19 };
// CPARAM fan_speed_max = { 0, 999, FAN_SPEED_MAX_DEFAULT, FAN_SPEED_MAX_DEFAULT, 20, 21 };
//

#define FAN_CURRENT_MIN_DEFAULT 30UL
#define FAN_CURRENT_MAX_DEFAULT 71UL

#define SLP_TIMEOUT_DEFAULT 10

#define KEY_DDR         DDRB
#define KEY_PORT        PORTB
#define KEY_PIN         PINB
#define KEY_UP          5
#define KEY_DOWN        2
#define ALL_KEYS        (1<<KEY_DOWN | 1<<KEY_UP)

#define REPEAT_MASK     (1<<KEY_DOWN | 1<<KEY_UP)
#define REPEAT_START    20	// after 20*20.48ms = 409.6ms
#define REPEAT_NEXT     8	// every 6*20.48ms = 122.88ms

#endif				// youyoue858d_h
